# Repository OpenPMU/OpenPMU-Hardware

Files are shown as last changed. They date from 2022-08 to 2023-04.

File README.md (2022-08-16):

# OpenPMU Hardware
Reference materials for the OpenPMU V2 hardware for use by qualified professionals.

**Disclaimer:**  These files are **not** intended as a guide for how to build the hardware.  Such activities should only be conducted by suitably qualified professionals in a laboratory environment.

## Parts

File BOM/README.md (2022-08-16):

Bill of materials.  

Prices for components will vary.

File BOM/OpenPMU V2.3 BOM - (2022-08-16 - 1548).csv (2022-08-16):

Item | Vendor | Unit Price | Qty | Total | Note | Link | Total | £298.75
OpenPMU BBB ADC Cape
6P6C Double Connector (RJ12) | Farnell | £1.99 | 1 | £1.99 | J1 | https://uk.farnell.com/molex/43223-6101/connector-rj11-jack-6p6c-cat3/dp/2612385?MER=sy-me-pd-mi-alte
47 uF 6.3 V 5 mm Capacitor | Farnell | £0.05 | 2 | £0.09 | C6,C7 | https://uk.farnell.com/teapo/kss476m6r3s1a5c07k/cap-47-f-6-3v-20/dp/2901342
LED SMD (G) | Farnell | £0.23 | 1 | £0.23 | BBB | https://uk.farnell.com/wurth-elektronik/150120gs75000/led-1206-green-450mcd-520nm/dp/2322085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
LED SMD (Y) | Farnell | £0.23 | 1 | £0.23 | PPS | https://uk.farnell.com/wurth-elektronik/150120ys75000/led-1206-yellow-120mcd-590nm/dp/2322089?st=LED,%20yellow,%20SMD,%201206
LED SMD (W) | Farnell | £0.94 | 1 | £0.94 | RU1 | https://uk.farnell.com/lumex/sml-lx1206uww-tr/led-white-2mm-90mcd-550nm/dp/2062228?st=SMD%20LED
LED SMD (B) | Farnell | £0.23 | 1 | £0.23 | RU0 | https://uk.farnell.com/wurth-elektronik/150120bs75000/led-1206-blue-145mcd-470nm/dp/2322084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
1K SMD Resistor 1206 | Farnell | £0.02 | 4 | £0.10 | R9,R10,R11,R12 | https://uk.farnell.com/bourns/cr1206-fx-1001elf/res-1k-1-0-25w-1206-thick-film/dp/2008393?st=Resistor%201001,%201206
30 contact, 2-row, 2.54mm board to board connector | Farnell | £2.00 | 1 | £2.00 | ADC7606-A | http://uk.farnell.com/samtec/ssw-115-01-t- d/socket-2-54mm-2x15way/dp/1885920
16 contact, 2-row, 2.54mm board to board connector | Farnell | £1.00 | 1 | £1.00 | ADC7606-B | http://uk.farnell.com/samtec/ssw-108-01-t- d/connector-rcpt-16pos-2row-2- 54mm/dp/2748580
46 contact, 2-row, 2.54mm board to board connector | Farnell | £3.52 | 2 | £7.04 | P8,P9 | https://uk.farnell.com/samtec/tsw-123-07-t-d/connector-header-46pos-2row-2/dp/2505042?st=46%20way%20header
1K Resistor Network DIP | Farnell | £0.96 | 1 | £0.96 |  | https://uk.farnell.com/bourns/4116r-1-102lf/resistor-network-1k/dp/9355820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
12-way, 2.54mm, right angle connector | Farnell | £0.17 | 1 | £0.17 | GPS_INPUT,CLK_SEL,RNG_SEL | https://uk.farnell.com/multicomp/mc34757/header-1-row-r-angle-12way/dp/1593434
AD7606 Module | eBay | £12.81 | 1 | £12.81 |  | https://www.ebay.co.uk/itm/16Bits-ADC-8CH-Synchronization-AD7606-DATA-Acquisition-Module-200Ksps/321889631963
Input Board
Fuse | Farnell | £0.28 | 3 | £0.84 | R1,R3,R5 | https://uk.farnell.com/bel-fuse-circuit-protection/0679l1000-01/fuse-smd-1a-fast-acting-2410/dp/2834805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
Thin Film 51k? resistor, package 2512, Series SMD, 1.5W | Farnell | £0.25 | 3 | £0.75 | R2,R4,R6 | https://uk.farnell.com/multicomp/mcpwr12ftea5102/res-51k-1-1-5w-2512-thick-film/dp/1887835?st=2512%2051k
Thin Film 499? resistor, package 2512, Series SMD, 1.5W | Farnell | £0.33 | 3 | £0.99 | R7,R8,R9 | https://uk.farnell.com/vishay/crcw2512499rfkeg/res-499r-1-1w-2512-thick-film/dp/2112880?st=2512%20499%20ohm
Thin Film 200? resistor, package 2512, Series SMD, 2W | Farnell | £0.47 | 4 | £1.88 | R10,R11,R12,R13 | https://uk.farnell.com/te-connectivity/3521200rft/res-200r-1-2w-2512/dp/2117485?st=2512%20200%20ohm
6P6C Double Connector (RJ12) | Farnell | £1.99 | 1 | £1.99 | J1 | https://uk.farnell.com/molex/43223-6101/connector-rj11-jack-6p6c-cat3/dp/2612385?MER=sy-me-pd-mi-alte
6 Contact Terminal Block (5mm) | Farnell | £1.18 | 1 | £1.18 | P | https://uk.farnell.com/buchanan-te-connectivity/282836-6/terminal-block-wire-to-brd-6pos/dp/3089071
8 Contact Terminal Block (2.54 mm) | Farnell | £1.87 | 1 | £1.87 |  | https://uk.farnell.com/multicomp-pro/mp008517/tb-wire-to-brd-r-a-8way-18awg/dp/3817464
Voltage Input - TV19 Transformer (4-pack) | eBay | £9.20 | 1 | £9.20 | (req. 3 units, but sold as 4 pack) | https://www.ebay.co.uk/itm/4pcs-TV19-Current-Type-Voltage-Transformer-Rated-Input-Current-Module-5mA/283459466643
Current Input - SCT-013-000 100A CT (Color: 100A Version) | eBay | £3.57 | 3 | £10.71 | (optional) | https://www.ebay.com/itm/1pcs-SCT-013-000-YHDC-30A-50A-100A-retractable-current-transformer-SCT013000/184085056080
3.5 mm Jack (Audio Connector) | Farnell | 1.77 | 15 | 26.55 | (optional, for CTs) | https://uk.farnell.com/cliff-electronic-components/fc681374v/conn-phone-audio-3-5mm-jack-3pos/dp/2431939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,%203%20contacts
Cables
Mini-USB (right angle) to USB Type A | Farnell | £1.91 | 1 | £1.91 | BBB to Raspberry Pi | https://uk.farnell.com/pro-signal/psg91618/lead-usb2-0-a-male-rt-angle-mini/dp/3403454
RJ11 6P6C Cable (Colour: Black, Length: 20cm) | eBay | £2.39 | 1 | £2.39 | Input Board to OpenPMU Cape | https://www.ebay.co.uk/itm/Short-15cm-20cm-50cm-70cm-6Pin-RJ11-to-RJ11-6P6C-Data-Cable-Straight-Pins/392564457959
Single Board Computers
BeagleBone Black | Farnell | £48.65 | 1 | £48.65 |  | https://uk.farnell.com/beagleboard/bbone-black-4g/beaglebone-black-rev-c-cortex/dp/2422228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
Raspberry Pi 4 (8 GB) | Farnell | £73.78 | 1 | £73.78 |  | https://uk.farnell.com/raspberry-pi/rpi4-modbp-8gb/raspberry-pi-4-model-b-cortex/dp/3369503
Raspberry Pi PSU (UK) | Farnell | £7.81 | 1 | £7.81 |  | https://uk.farnell.com/raspberry-pi/sc0212/rpi-power-supply-usb-c-5-1v-3a/dp/3106940
GNSS Module (GPS)
UBLOX 7M GPS Module | eBay | £5.50 | 1 | £5.50 |  | https://www.ebay.co.uk/itm/NEO-7M-GPS-Satellite-Positioning-Module-for-Arduino-STM32-C51-Replace-NEO-6M/311876309386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
Active GPS Antenna | eBay | £8.68 | 1 | £8.68 |  | https://www.ebay.co.uk/itm/GPS-Active-Antenna-BNC-series-connector-2M-3M-5M-for-Garmin-GPS-45XL-225-/300415623305
Patch Wires | Farnell | £3.49 | 1 | £3.49 |  | https://uk.farnell.com/multicomp-pro/mp006284/jumper-wire-kit-female-to-female/dp/3617772
Enclosure
Plastic Enclosure | Farnell | £37.64 | 1 | £37.64 |  | https://uk.farnell.com/spelsberg/130-008/box-smoked-lid-254x180x90mm/dp/531560
M3x8mm Screws (Hex Head) 50-pack | Farnell | £4.22 | 1 | £4.22 |  | https://uk.farnell.com/duratool/d01433/screws-button-m3-8mm/dp/2444343?st=m3%20screw
M3 Nylon Standoff 20mm | Farnell | £11.53 | 1 | £11.53 |  | https://uk.farnell.com/tr-fastenings/fahsngffm3-20-6/standoff-hex-female-nylon-6-20mm/dp/2480025
M3 Nylon Screw (Phillips) | Farnell | £3.00 | 1 | £3.00 |  | https://uk.farnell.com/duratool/d00687/screw-pan-m3x6-pk25/dp/1514409?st=m3%20nylon%20screw
Rubber Feet (24-pack) | Farnell | £5.44 | 1 | £5.44 |  | https://uk.farnell.com/hammond/1421t2/feet-rubber-12-7x3-5-black-pk24/dp/1876514?st=rubber%20feet
Cable Gland M20 | Farnell | £0.96 | 1 | £0.96 |  | https://uk.farnell.com/lapp-kabel/53112911/cable-gland-spiral-black-m20/dp/1504199

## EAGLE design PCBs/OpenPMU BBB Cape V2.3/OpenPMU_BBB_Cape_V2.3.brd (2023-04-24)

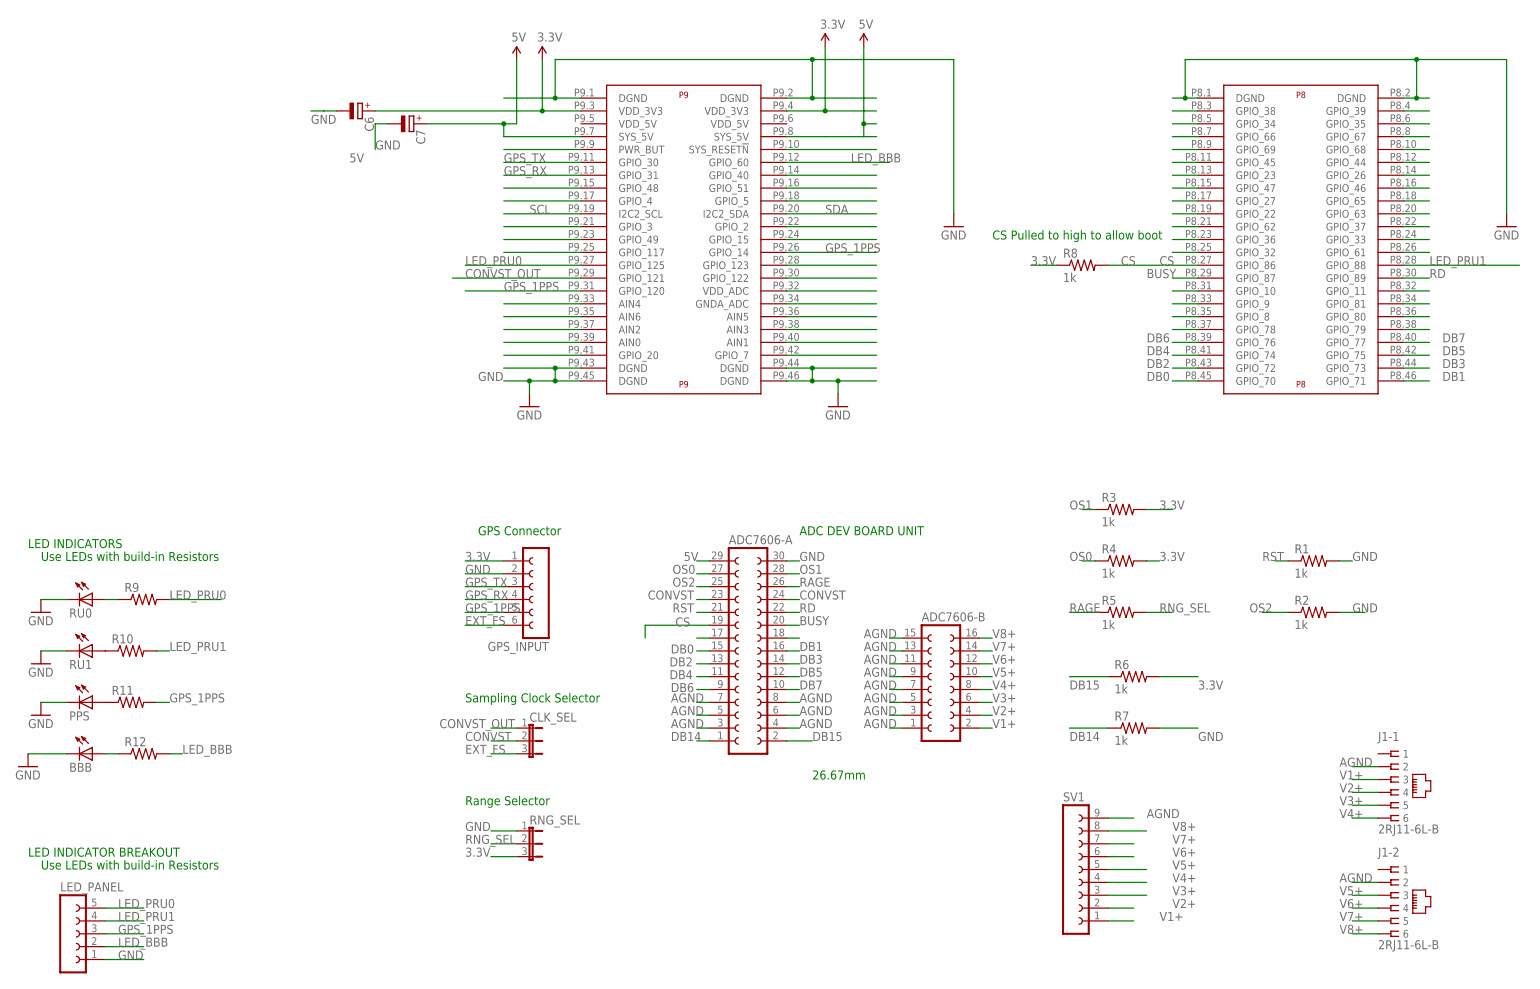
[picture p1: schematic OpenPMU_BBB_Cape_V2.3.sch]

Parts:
ADC7606-A: FE15-2
ADC7606-B: FE08-2
BBB: LEDCHIPLED_1206; CHIPLED_1206
C6, C7: CPOL-EUE1.8-4; E1,8-4
CLK_SEL: JP2E; JP2
GPS_INPUT: FE06-1; FE06
J1: 2RJ11-6L-B; 2RJ11
LED_PANEL: FE05-1
PPS: LEDCHIPLED_1206; CHIPLED_1206
R1, R2, R3, R4, R5, R6, R7, R8: 1k; 0204/7
R9, R10, R11, R12: R-US_M1206; M1206
RNG_SEL: JP2E; JP2
RU0, RU1: LEDCHIPLED_1206; CHIPLED_1206
SV1: FE09-1; FE09
U$1: BEAGLE_BONE_BLACK_CAPE

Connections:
3.3V: C6.+, GPS_INPUT.1, R3.2, R4.2, R6.2, R8.1, RNG_SEL.3, U$1.P9.3 (VDD_3V3), U$1.P9.4 (VDD_3V3)
5V: ADC7606-A.29, C7.+, U$1.P9.7 (SYS_5V), U$1.P9.8 (SYS_5V)
AGND: ADC7606-A.3, ADC7606-A.4, ADC7606-A.5, ADC7606-A.6, ADC7606-A.7, ADC7606-A.8, ADC7606-B.1, ADC7606-B.3, ADC7606-B.5, ADC7606-B.7, ADC7606-B.9, ADC7606-B.11, ADC7606-B.13, ADC7606-B.15, J1.1-2 (2), J1.2-2 (2), SV1.9
BUSY: ADC7606-A.20, U$1.P8.29 (GPIO_87)
CONVST: ADC7606-A.23, ADC7606-A.24, CLK_SEL.2
CONVST_OUT: CLK_SEL.1, U$1.P9.29 (GPIO_121)
CS: ADC7606-A.19, R8.2, U$1.P8.27 (GPIO_86)
DB0: ADC7606-A.15, U$1.P8.45 (GPIO_70)
DB1: ADC7606-A.16, U$1.P8.46 (GPIO_71)
DB2: ADC7606-A.13, U$1.P8.43 (GPIO_72)
DB3: ADC7606-A.14, U$1.P8.44 (GPIO_73)
DB4: ADC7606-A.11, U$1.P8.41 (GPIO_74)
DB5: ADC7606-A.12, U$1.P8.42 (GPIO_75)
DB6: ADC7606-A.9, U$1.P8.39 (GPIO_76)
DB7: ADC7606-A.10, U$1.P8.40 (GPIO_77)
DB14: ADC7606-A.1, R7.1
DB15: ADC7606-A.2, R6.1
EXT_FS: CLK_SEL.3, GPS_INPUT.6
FRST: ADC7606-A.18
GND: ADC7606-A.30, BBB.C, C6.-, C7.-, GPS_INPUT.2, LED_PANEL.1, PPS.C, R1.2, R2.2, R7.2, RNG_SEL.1, RU0.C, RU1.C, U$1.P8.1 (DGND), U$1.P8.2 (DGND), U$1.P9.1 (DGND), U$1.P9.2 (DGND), U$1.P9.43 (DGND), U$1.P9.44 (DGND), U$1.P9.45 (DGND), U$1.P9.46 (DGND)
GPS_1PPS: GPS_INPUT.5, LED_PANEL.3, R11.2, U$1.P9.26 (GPIO_14), U$1.P9.31 (GPIO_120)
GPS_RX: GPS_INPUT.4, U$1.P9.13 (GPIO_31)
GPS_TX: GPS_INPUT.3, U$1.P9.11 (GPIO_30)
LED_BBB: LED_PANEL.2, R12.2, U$1.P9.12 (GPIO_60)
LED_PRU0: LED_PANEL.5, R9.2, U$1.P9.27 (GPIO_125)
LED_PRU1: LED_PANEL.4, R10.2, U$1.P8.28 (GPIO_88)
unnamed: R9.1, RU0.A
unnamed: R10.1, RU1.A
unnamed: PPS.A, R11.1
unnamed: BBB.A, R12.1
OS0: ADC7606-A.27, R4.1
OS1: ADC7606-A.28, R3.1
OS2: ADC7606-A.25, R2.1
RAGE: ADC7606-A.26, R5.1
RD: ADC7606-A.22, U$1.P8.30 (GPIO_89)
RNG_SEL: R5.2, RNG_SEL.2
RST: ADC7606-A.21, R1.1
SCL: U$1.P9.19 (I2C2_SCL)
SDA: U$1.P9.20 (I2C2_SDA)
V1+: ADC7606-B.2, J1.1-3 (3), SV1.1
V2+: ADC7606-B.4, J1.1-4 (4), SV1.2
V3+: ADC7606-B.6, J1.1-5 (5), SV1.3
V4+: ADC7606-B.8, J1.1-6 (6), SV1.4
V5+: ADC7606-B.10, J1.2-3 (3), SV1.5
V6+: ADC7606-B.12, J1.2-4 (4), SV1.6
V7+: ADC7606-B.14, J1.2-5 (5), SV1.7
V8+: ADC7606-B.16, J1.2-6 (6), SV1.8
VI0: ADC7606-A.17

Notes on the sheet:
ADC DEV BOARD UNIT
GPS Connector
CS Pulled to high to allow boot
Sampling Clock Selector
LED INDICATORS
LED INDICATOR BREAKOUT
Use LEDs with build-in Resistors
26.67mm
Range Selector

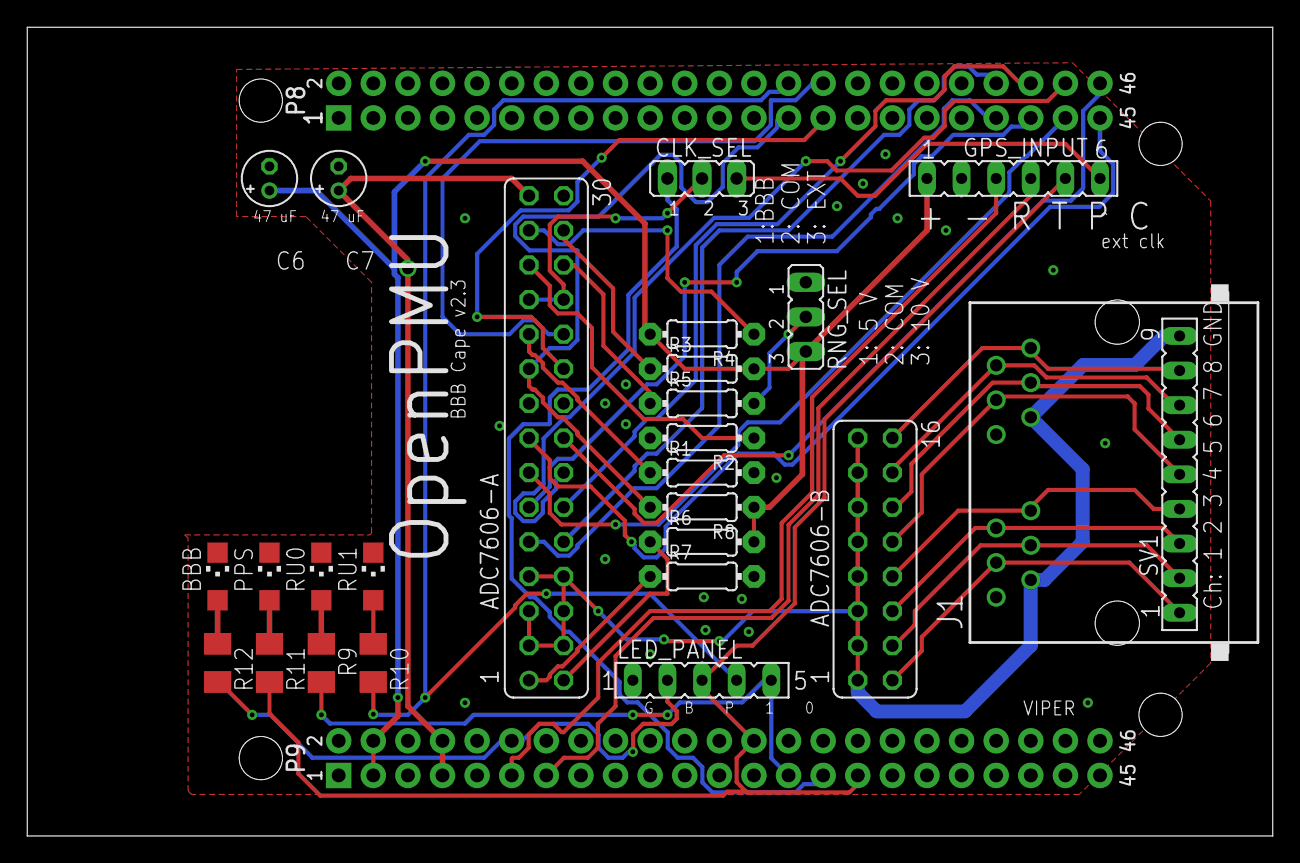
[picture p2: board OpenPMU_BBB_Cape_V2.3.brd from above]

Board: 2 copper layers, 91.4 x 59.3 mm, 27 parts (0 on the bottom side), 44 nets.

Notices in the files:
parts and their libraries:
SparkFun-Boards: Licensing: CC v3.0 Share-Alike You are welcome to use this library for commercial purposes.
